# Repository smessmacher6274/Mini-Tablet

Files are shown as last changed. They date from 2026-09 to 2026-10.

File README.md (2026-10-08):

# ESP32 Note Tablet

A touchscreen note pad and to-do display built with an Inland ESP32-WROOM-32E,
a Hosyond 4-inch ST7796S display, and XPT2046 resistive touch. Firmware uses
ESP-IDF and CMake. A local Python server provides a browser task editor,
SQLite storage, and an MQTT broker.

The project began on a Raspberry Pi Pico W; the active firmware is now ESP32.
This README describes the current implementation. The original Pico code is
preserved under `Code/legacy/pico/`.

## Current features

| Feature | Status |
| --- | --- |
| Portrait display | 320 × 480, SPI ST7796S |
| Pen input | Three-point touch calibration at each boot |
| Home menu | To-do list, Draw Notes, Clock |
| Drawing | Black pen, area eraser, Home button |
| Notes across navigation | Preserved in RAM, including the idle screen |
| Idle screen | Appears after 60 seconds without touch; not deep sleep |
| Clock | Placeholder until time is set; automatic time sync is not implemented |
| Computer task editor | Add, edit, complete/reopen, delete, and filter tasks |
| Task storage | SQLite on the computer |
| Wi-Fi/MQTT | Authenticated LAN subscription and tablet receipt status |
| Tablet to-do view | Two tasks per page, Prev/Next; tap a checkbox to complete/reopen online |
| BLE | Greeting plus text task entry; 20 device-local RAM tasks with offline checkboxes |
| BLE Wi-Fi setup | Encrypted SSID/password writes and Apply; settings last until reset |
| iPhone app, dictation, handwriting recognition | Planned |
| Tablet flash persistence | Deferred: notes, tasks, and calibration are not saved by the app |

Display/BLE, navigation, MQTT delivery, task completion and partial redraws have
been confirmed on hardware. BLE task entry builds and passes host tests; its
phone-to-tablet path still needs checking after flashing this update.

## Project layout

```text
2040Bluetooth/
├── README.md                 Main setup and usage guide
├── Code/                     Active ESP-IDF CMake project
│   ├── main/                 Display, touch, UI, BLE, Wi-Fi/MQTT, task parser
│   ├── tests/                Host-side UI and task-parser tests
│   ├── setup_network.py      Generate local firmware network configuration
│   ├── sdkconfig.defaults*   Firmware configuration defaults
│   ├── dependencies.lock    Managed component versions
│   ├── PLAN.md              Earlier detailed roadmap; see status here first
│   └── legacy/pico/         Previous Pico firmware
├── LocalMQTT/                Python server, browser UI, and integration tests
│   ├── server.py             HTTP API + SQLite + embedded aMQTT broker
│   ├── static/               Browser interface
│   ├── setup_lan.py          Generate MQTT credentials and configure LAN IP
│   ├── allow-mqtt.ps1        Windows firewall rule, requires Administrator
│   ├── check_connection.py   Read-only authenticated MQTT connection check
│   ├── run.cmd               Start the Windows server
│   └── data/                 Generated database and local credentials
├── Case/                     Enclosure/pen-holder STL files
└── Kicad/                    Reserved for electronics design files
```

Generated build folders and the old Pico SDK may also be present. Always run
ESP-IDF commands from **Code**, not the workspace root. This guide uses
`Code/build-esp32-wsl`; `compile.sh` instead defaults to `Code/build-esp32`.

## Hardware and wiring

Use the **GPIO/IO labels**, not physical header positions. Disconnect USB before
rewiring. These connections target the original ESP32-WROOM-32E, not ESP32-S3.

| Display pin | ESP32 connection |
| --- | --- |
| VCC | 5V, for the project's identified display module |
| GND | GND |
| CS | IO27 |
| RESET / RST | IO25 |
| DC / RS | IO26 |
| SDI / MOSI | IO23 |
| SCK | IO18 |
| LED | 3V3 |
| SDO / MISO | Leave disconnected |
| T_CLK | IO14 |
| T_DIN | IO13 |
| T_DO | IO19 |
| T_CS | IO32 |
| T_IRQ | IO33 |

ESP32 GPIO signals are 3.3V; do not apply 5V to signal pins. Confirm the supply
requirements if using a different display module. The LCD uses SPI2 at 1 MHz;
touch uses a separate SPI3 bus. Keep the touch wires on the pins above.

Both modules need secure, soldered headers. Direct jumpers resolved the earlier
white-screen problem; the breadboard or a jumper was suspected. A lit backlight
does not prove that SPI communication works. Pin definitions are in
[`Code/main/board.h`](Code/main/board.h).

## How the current connection works

```text
Computer browser at localhost:8080
                  |
          HTTP API + SQLite
                  |
       MQTT broker on computer
                  |
         Home router / LAN
                  |
         ESP32 Wi-Fi client
                  |
         Tablet to-do screen
```

The ESP32 joins your existing 2.4 GHz Wi-Fi. It does **not** create a network
that appears in the computer's Wi-Fi list. The computer may use Ethernet or
another Wi-Fi band if both devices can communicate on the same LAN.

`localhost` means the computer where the browser/server runs. The ESP32 uses
the computer's **LAN IPv4 address**, not localhost and not the public internet
IP. `192.168.1.148` was the development computer's address; confirm it using
Windows `ipconfig` under the active Wi-Fi/Ethernet adapter.

The computer must remain awake with the server running for syncing. The tablet
keeps its last received tasks in RAM during disconnection; after reboot it
needs to reconnect to receive them again. The phone is not part of this path yet.

## 1. Start the local server — Windows PowerShell

The following paths match this development computer; change them for another
checkout. Python 3.11 was used for the verified server environment.

For a fresh environment:

```powershell
cd C:\Users\messm\OneDrive\Desktop\2040Bluetooth\LocalMQTT
python -m venv .venv
.\.venv\Scripts\python.exe -m pip install -r requirements-lock.txt
```

Skip those installation steps if `.venv` is already installed. Provision the
LAN address and start the server:

```powershell
ipconfig
# Replace this address if your active adapter shows a different IPv4 address.
.\.venv\Scripts\python.exe setup_lan.py --host 192.168.1.148
.\.venv\Scripts\python.exe server.py --lan
```

Open [http://localhost:8080](http://localhost:8080). Leave the terminal running;
Ctrl+C stops it. On later runs, double-click `LocalMQTT/run.cmd` or run the final
command above. Run only one server instance. If the page is already available,
check the existing instance before launching another.

The server also supports loopback-only development without `--lan`, but the
ESP32 cannot connect to that mode. MQTT LAN mode uses generated credentials and
topic permissions; HTTP remains accessible only on the computer.

### Allow MQTT through Windows Firewall

Run once from **Administrator PowerShell**:

```powershell
cd C:\Users\messm\OneDrive\Desktop\2040Bluetooth\LocalMQTT
powershell.exe -NoProfile -ExecutionPolicy Bypass -File .\allow-mqtt.ps1
```

This allows inbound TCP 1883 to the configured LAN address from the local
subnet. The execution-policy override applies only to that command's process.
The earlier automatic firewall attempt lacked Administrator rights; do not
assume the rule exists until this succeeds.

## 2. Configure and flash the tablet — WSL Bash

The verified firmware toolchain is the installed ESP-IDF 6.1 development
checkout at `~/esp32/esp-idf`. It uses the **esp32** target, not esp32s3.
See [Espressif's setup guide](https://docs.espressif.com/projects/esp-idf/en/stable/esp32/get-started/index.html)
for a new toolchain installation. Activate the existing installation in each
new WSL shell:

```bash
source ~/esp32/esp-idf/export.sh
idf.py --version
```

If activation reports that its Python virtual environment is missing:

```bash
cd ~/esp32/esp-idf
./install.sh esp32
source ./export.sh
```

Connect the ESP32 USB device to WSL using your USB forwarding setup. Windows
COM5 and WSL `/dev/ttyUSB0` are names on different operating systems; use the
port that actually appears in your current shell:

```bash
ls /dev/ttyUSB* /dev/ttyACM* 2>/dev/null
```

Configure the firmware, then build and flash:

```bash
cd /mnt/c/Users/messm/OneDrive/Desktop/2040Bluetooth/Code
python3 setup_network.py
idf.py -B build-esp32-wsl -p /dev/ttyUSB0 flash monitor
```

The setup script asks for the Wi-Fi network name, a hidden Wi-Fi password, and
the computer LAN IP. Press Enter to accept the bracketed IP if it is correct.
It imports the MQTT credentials from `LocalMQTT/data/connection.json` and writes
`Code/main/network_config.h`. That header is required for compilation; missing
or empty network settings must be corrected before building. Older builds
silently disabled Wi-Fi and displayed `WIFI NOT SET` when it was missing.

Build without flashing with `idf.py -B build-esp32-wsl build`. ESP32 output is
flashed over serial; do not look for a Pico-style `.uf2` file. Exit the serial
monitor with **Ctrl+]**. If automatic flashing cannot connect, hold BOOT during
connection and release when flashing begins.

## Daily use

1. Start the computer server and leave it running.
2. Power the tablet. Hold the stylus on each red cross, then lift when it advances.
   These three points map raw touch readings to screen coordinates.
3. Tap the idle screen to open the menu.
4. Open **To-do List** to see tasks, completion state, and Prev/Next pages.
   Tap and lift on a checkbox to complete/reopen a task. The box changes after
   server confirmation; keep the server running. Offline taps are not queued.
5. Add or change tasks in the computer browser. The tablet receives new snapshots.
6. Open **Draw Notes** to draw. Tap and lift on **Write**, **Erase**, or **Home**.
   Erase is an area eraser, not a whole-page clear button.

The note survives Home and the 60-second idle timeout. Power loss/reset clears
it and restarts calibration. The idle screen does not turn off the backlight.
Task titles support up to 120 UTF-8 bytes on the server, with at most 50 tasks;
the tablet's bitmap font substitutes `?` for unsupported characters.

To-do updates use partial redraws: completion repaints only the affected checkbox
and text; title changes clear that row. Unchanged snapshots do not repaint the
list. Page changes repaint the list area while keeping navigation buttons.
The display SPI clock remains at the conservative 1 MHz setting.

Successful connection logs include `Wi-Fi ready`, `MQTT connected`, and
`Received ... tasks`. Browser status distinguishes publication to the broker
from the revision received by the tablet. Receipt confirms arrival in the
tablet's RAM queue, not a flash write or proof that pixels have been rendered.

## BLE and the proposed iPhone workflow

Current BLE service:

| Setting | Value |
| --- | --- |
| Advertising name | `NoteTablet-BLE` |
| Service UUID | `12345678-1234-5678-1234-56789abcdef0` |
| Read characteristic | `12345678-1234-5678-1234-56789abcdef1` |
| Greeting | `What it do` |

Use a BLE GATT scanner to read the greeting and write tasks. This is a custom
GATT service, not a keyboard/audio profile. BLE stays enabled with Wi-Fi/MQTT.

Portable task entry is now available through a BLE testing app: write plain
text to characteristic `12345678-1234-5678-1234-56789abcdef2`. Local tasks can
be completed offline and survive phone disconnects and MQTT updates, but not
reset. They are not uploaded to the computer yet. See [BLE setup and protocol](Code/BLE.md).
The greeting remains at `...def1`; write status is readable at `...def3`.
BLE Wi-Fi configuration uses characteristics `...def4` through `...def7`; see
the BLE guide for pairing, write order, and status. Settings last until reset.
A polished companion app and persistent network configuration are future features.
MQTT still runs over Wi-Fi/TCP, independently of BLE.

## Data, credentials, and protocol

- `LocalMQTT/data/tasks.sqlite3`: authoritative tasks and revisions on the PC.
- `LocalMQTT/data/connection.json`: local MQTT credentials and server address.
- `LocalMQTT/data/passwords.txt`: broker password hashes.
- `Code/main/network_config.h`: generated Wi-Fi/MQTT configuration.

Credential files are ignored by their component `.gitignore` files. Compiled
firmware also contains credentials; do not publish it or those files. Back up
the database with the server stopped. Tablet drawings are not in this database.

MQTT uses retained QoS 1 snapshots at
`notepad/v1/devices/tablet-001/state`. The tablet publishes heartbeat/received
revision at `notepad/v1/devices/tablet-001/presence`, including an offline Last
Will. The service is allowed to publish state; tablet credentials cannot edit
it directly. Completion requests use non-retained QoS 1 messages at
`notepad/v1/devices/tablet-001/commands`, with an item ID, base revision, and
explicit desired completion state. Stale requests are rejected and current
state is republished; repeated messages cannot toggle a task twice.
Server restart reconstructs retained state from SQLite.

This is a trusted-LAN prototype using unencrypted MQTT. Do not port-forward it
to the internet. The browser editor is localhost-only, so opening the same URL
on an iPhone will not reach this computer.

See [`LocalMQTT/README.md`](LocalMQTT/README.md) for the JSON snapshot format,
HTTP API, process management, and server details.

## Troubleshooting

| Symptom | What to check |
| --- | --- |
| No ESP32 network in the Wi-Fi list | Expected: the tablet joins your router; it is not an access point. |
| `idf.py: command not found` | Source the WSL ESP-IDF `export.sh` in this terminal. |
| PowerShell syntax errors in Bash | Use WSL commands in Bash and Windows commands in PowerShell. |
| `CMakeLists.txt not found` | Change into the project's `Code` directory. |
| No `/dev/ttyUSB0` | Check USB cable and USB forwarding into WSL; COM5 is a Windows name. |
| Port not readable | Check `ls -l /dev/ttyUSB0` and serial-group membership; if owned by `dialout`, add your user with `sudo usermod -aG dialout "$USER"`, then start a new login session. |
| `WIFI NOT SET` | Run `setup_network.py`, rebuild, and flash. |
| `WIFI CONNECTING` | Verify SSID/password and 2.4 GHz availability. |
| `MQTT CONNECTING` | Check server `--lan`, LAN IP, firewall, and router client isolation. |
| White display but BLE works | Check LCD power, ground, CS/DC/reset/SPI wires; previously direct jumpers fixed this. |
| Calibration does not advance | Check the separate touch wiring, especially T_IRQ and T_CS. |
| Notes disappear after reboot | Expected until flash persistence is implemented. |
| Port 8080/1883 is occupied | An existing server may already be running; see the server README before stopping it. |

If the computer LAN IP changes, rerun `setup_lan.py --host NEW_IP`, restart the
server, rerun the firewall script, then rerun tablet setup and flash. Updating
only the firmware IP does not change the server's listening address.

## Validation and development

Server integration tests use temporary databases and MQTT clients:

```powershell
cd C:\Users\messm\OneDrive\Desktop\2040Bluetooth\LocalMQTT
.\.venv\Scripts\python.exe -m unittest -v test_server
.\.venv\Scripts\python.exe check_connection.py
```

The connection check requires the real server running. It verifies authenticated
subscription on its LAN address without editing tasks; it does not prove the
Windows firewall admits traffic from another device.

Host UI/parser tests in WSL, from `Code` (managed cJSON is fetched by ESP-IDF
during the firmware build):

```bash
gcc -std=gnu11 -Itests/stubs -Imain tests/ui_test.c main/ui.c -o /tmp/tablet-ui-test
/tmp/tablet-ui-test
gcc -std=gnu11 -Imain -Imanaged_components/espressif__cjson/cJSON tests/todo_test.c main/todo_model.c managed_components/espressif__cjson/cJSON/cJSON.c -o /tmp/tablet-todo-test
/tmp/tablet-todo-test
```

Previously verified: ESP32 MQTT firmware build; UI navigation, input suppression,
pagination, note restore, and idle tests; task-parser tests; four server tests
covering CRUD, revisions, validation, retained delivery, restart, authentication,
topic permissions, and presence. Hardware tests remain necessary after flashing.

## Next milestones

1. Confirm portable BLE task entry on the physical tablet and iPhone.
2. Add an iPhone companion app and synchronize device-local tasks with the server.
3. Add shared task IDs, acknowledgments, and conflict handling before two-way edits.
4. Add persistent Wi-Fi configuration and real clock/timezone synchronization.
5. Add flash persistence for calibration, tasks, and note pages when ready.
6. Add multiple notes and export; handwriting-to-text is a later feature.

The earlier design is retained in [`Code/PLAN.md`](Code/PLAN.md). Its proposed
cloud/web-app and Mosquitto architecture is not the current deployment; today
the broker is embedded aMQTT and the browser editor runs locally on the PC.

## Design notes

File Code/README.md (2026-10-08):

# ESP32 note tablet: portrait ST7796S + BLE

Current build defaults to Bluetooth test mode: boot directly to To-do, skip
calibration, disable touch, Wi-Fi and MQTT, and keep the screen awake.
Wi-Fi credential characteristics are omitted during this test. See [BLE.md](BLE.md)
for the stability checks. Set `TABLET_BLE_TEST_MODE` to 0 in `main/test_mode.h`
to restore the calibration/menu/idle behavior described below.

## Current milestone: MQTT task display

See `PLAN.md` for the iPhone / MQTT roadmap and synchronization design.
After calibration, tap the idle clock screen to open the menu. Choose To-do
List or Draw Notes. Notes has Write, Erase and Home controls. Drawings survive
navigation and the 60-second idle timeout in a 16,960-byte monochrome RAM buffer.
Reset/power loss still clears the note. The idle screen is not hardware sleep.

The To-do view receives the computer's list over Wi-Fi/MQTT, with two tasks per
page and Prev/Next controls. Tap a checkbox to complete/reopen while connected;
the server-confirmed snapshot updates the display. Titles are edited in the browser.
See `../LocalMQTT/README.md` for the server and Windows firewall setup.
Run `python3 setup_network.py` in this directory before flashing to enter Wi-Fi
credentials locally and import the generated MQTT credentials. This configuration
is required to build; older firmware silently disabled Wi-Fi when it was missing.
The clock still displays `--:--` / `TIME NOT SET`; time synchronization is later.
BLE now supports text task entry from a phone testing app, with offline local
checkboxes. See [BLE.md](BLE.md). Local tasks remain in RAM and are separate
from the computer's list; a companion app and cross-transport sync are later.

Flash from the activated WSL shell, inside the **Code** directory:

```bash
idf.py -B build-esp32-wsl -p /dev/ttyUSB0 flash monitor
```

Validation: host UI tests cover tap/release suppression across navigation,
Write/Erase switching, note-restore calls, and inactivity return to the clock.
Hardware check: draw, return Home, revisit Notes, erase, wait 60 seconds, then
open Notes again and confirm the image survives. Reset should clear it.

Target hardware: **Inland ESP32 board with ESP32-WROOM-32E module**.
The project now uses ESP-IDF (CMake), not the Pico SDK or Arduino.
The MQTT build is verified with your ESP-IDF 6.1 development checkout.
ESP32-S3 also has an optional pin map,
but the default and the wiring below are for your original ESP32.
No PSRAM is required or enabled. Default flash size is a conservative 4 MB;
confirm actual flash size before increasing it.

## Wire the display (USB disconnected)

These are **GPIO labels**, not header position numbers. Do not retain the Pico
physical-pin wiring. Check labels on the Inland board before connecting.

| ST7796S module | ESP32-WROOM-32E development board |
| --- | --- |
| VCC | USB-derived 5V supply pin, after confirming the board pinout |
| GND | GND |
| CS | GPIO27 |
| RESET / RST | GPIO25 |
| DC / RS | GPIO26 |
| SDI / MOSI | GPIO23 |
| SCK | GPIO18 |
| LED | 3V3 |
| SDO / MISO | Unconnected |
| Touch pins | See pen-tracing section below |

The previously identified display module accepts 3.3–5V VCC; its LED control
uses 3.3V. ESP32 signal pins use 3.3V: never connect 5V to a GPIO.
Use soldered headers and secure short jumpers. Remove any SD card for this test.
The white-screen fault on the earlier wiring is not proven fixed by this port.
A lit backlight does not establish that the LCD controller has stable power.

## Install and activate ESP-IDF

Use Espressif's official setup instructions for ESP-IDF 5.4 and your OS:
https://docs.espressif.com/projects/esp-idf/en/v5.4/esp32/get-started/index.html

The Arm compiler used for the Pico cannot compile this Xtensa ESP32 project.
In Linux/WSL, after installing ESP-IDF, activate it in each new shell:

```bash
source ~/esp/esp-idf/export.sh
```

On Windows, use the ESP-IDF terminal installed by Espressif. Native Windows
flashing is often simpler than forwarding a USB serial device into WSL.

## Build and flash

From this project directory in an activated ESP-IDF shell:

```bash
idf.py -B build-esp32 set-target esp32
idf.py -B build-esp32 build
idf.py -B build-esp32 -p /dev/ttyUSB0 flash monitor
```

Replace `/dev/ttyUSB0` with your board's serial port (`COM5`, for example, in
Windows). If automatic flashing fails, hold BOOT while connecting/resetting
and release when flashing begins. Exit the serial monitor with Ctrl+].
ESP32 uses serial flashing, not Pico BOOTSEL/UF2 drag-and-drop.

For subsequent Bash builds, `bash compile.sh` runs the build without deleting
anything. The old `build/` and `build-display/` directories contain Pico output;
do not use those binaries for the ESP32. The new build is `build-esp32/`.

## What to expect

- Portrait 320x480 screen with Hello and World! on separate lines and RGB bars.
- BLE device named **NoteTablet-BLE** (previously PicoW-BLE).
- Service: `12345678-1234-5678-1234-56789abcdef0`.
- Read characteristic: `12345678-1234-5678-1234-56789abcdef1`.
- Readable text: **What it do**, preserving your latest greeting edit.
- Advertising resumes after disconnection or a failed connection attempt.

Test by power cycling, leaving the display running for several minutes, reading
via a BLE scanner, disconnecting, and reconnecting. Check serial logs for resets
or brownout reports if the screen goes white. This demo has no pairing requirement
and no writable notes, persistent storage, or Wi-Fi yet.

## Source layout

- `main/main.c`: initialize the display once, then start BLE.
- `main/display.c`: SPI ST7796S driver, 1 MHz, RGB565, portrait; small scanline buffer.
- `main/board.h`: wiring by chip target.
- `main/ble.c`: NimBLE GATT service and connection/advertising callbacks.
- `sdkconfig.defaults`: BLE and build defaults, no dependency on PSRAM.

NimBLE runs in its own FreeRTOS task; no Pico async polling loop is needed.
The repeated display-reset loop found in your latest Pico code is not carried
into the ESP32 app. Only the display code owns SPI2; touch/SD integration later
will need shared-bus coordination. NVS currently contains only system data;
its initialization may erase/reinitialize NVS on a format/full-pages error.
Revisit that policy before storing user notes there.

The previous Pico sources, including your edits, are saved in `legacy/pico/`.
The Pico SDK and old build directories are left in place but unused. To rebuild
that snapshot, set PICO_SDK_PATH to the existing SDK and configure it separately.

Optional ESP32-S3 pin map: CS=10, MOSI=11, SCK=12, DC=9, RESET=8. Select it only
for actual S3 hardware with `idf.py -B build-esp32 set-target esp32s3`; changing
target regenerates sdkconfig. Do not use those pins on your WROOM-32E.

## Validation status

The port has been source-reviewed against ESP-IDF 5.4 NimBLE and SPI APIs.
The pen-tracing firmware compiled successfully with the installed WSL ESP-IDF 6.1 development checkout. Display/BLE operation was confirmed by the user before this change; touch calibration and drawing still need hardware verification.

References:
- https://github.com/espressif/esp-idf/tree/v5.4.2/examples/bluetooth/nimble/bleprph
- https://docs.espressif.com/projects/esp-idf/en/v5.4/esp32/api-reference/peripherals/spi_master.html

## Pen tracing (XPT2046 resistive touch)

Keep the working display connections. With USB unplugged, add these five
connections for the ESP32-WROOM-32E (GPIO labels, not header positions):

| Display touch pin | ESP32 |
| --- | --- |
| T_CLK | IO14 |
| T_DIN | IO13 |
| T_DO | IO19 |
| T_CS | IO32 |
| T_IRQ | IO33 |

Touch uses a separate SPI3 bus at 500 kHz. Do not connect T_CLK/T_DIN to the
LCD bus in this configuration. LCD SDO remains disconnected. If your display
has CTP_* labels instead of T_*, this driver is not for that touch variant.

Build/flash in the activated WSL ESP-IDF shell:

```bash
idf.py -B build-esp32-wsl -p /dev/ttyUSB0 flash monitor
```

At each boot the hello screen is followed by three red calibration crosses:
upper left, upper right, then lower left. Hold the stylus steadily on each cross
until it disappears, then lift. After all three, a white canvas appears; draw
with moderate stylus pressure to leave a black trace. It does not recognize
handwriting or save strokes yet. Press EN/reset to clear and recalibrate.
BLE remains active during calibration and drawing. If the first cross never
advances, check T_IRQ, T_CS and the other touch wires. The serial monitor logs
each calibration target and canvas readiness. Small sample filtering and a
three-point affine transform handle axis reversal and portrait orientation.

## Write and Erase tools

After calibration, the top toolbar has Write and Erase buttons. The selected
button is green. Tap and lift to select a tool, then use the canvas below:
Write draws a 3-pixel black stroke; Erase rubs out a 17-pixel-wide area.
Switching tools keeps the rest of the drawing. Neither tool can paint over
the toolbar. Reset still clears the page and restarts calibration; BLE stays on.

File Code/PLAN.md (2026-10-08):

# Note tablet roadmap

## Current priorities (October 5, 2026)

1. Stabilize Bluetooth, investigate duplicate task entry, and verify reconnects
   without power cycling. Temporarily skip calibration and idle clock switching.
2. Wire and bring up microSD external storage after confirming module/pin usage.
3. Persist received MQTT task state on the server and/or microSD.
4. Save touch calibration to flash/SD and restore it at boot.
5. Improve display refresh rates.
6. Synchronize and finish the clock.

Bluetooth soak-test mode is currently enabled in `main/test_mode.h`;
the normal product flow below resumes when it is disabled.

## Product flow

Boot -> touch calibration -> idle clock -> tap -> menu -> To-do or Notes.
Home returns to menu; Clock returns to idle. After 60 seconds without touch,
return to the clock. Preserve the current note across screen changes. This
idle screen is a UI state, not deep sleep: the existing backlight wiring stays on.

The owner uses an iPhone and has no existing MQTT infrastructure.

Local computer milestone implemented in `../LocalMQTT/`: browser CRUD, SQLite
persistence, retained MQTT state and restart/duplicate/conflict tests. The first
broker is embedded aMQTT to avoid an additional Docker/Mosquitto installation.
It binds only to loopback; ESP32 subscription and authenticated LAN access remain
next steps. This changes the initial broker implementation, not the MQTT format.

## Architecture

iPhone web app -> HTTPS API -> synchronization service + SQLite database
                                      |
                                  MQTT broker
                                      |
                              ESP32 over Wi-Fi

Start with Mosquitto and a small service on the development computer on the
same LAN. The host must remain running and reachable. Later move them to an
always-on machine or hosted service for access away from home. Do not expose
an unauthenticated broker publicly. Use per-device credentials/topic ACLs and
TLS outside an isolated local development setup. BLE remains available during
development; MQTT uses Wi-Fi, not the existing BLE greeting characteristic.

Use an iPhone-friendly web app first (add to Home Screen if desired). Text
entry can use the iPhone keyboard's dictation. No browser SpeechRecognition
dependency for the first release. Native iOS app/background notifications are
a later decision. Drawings stay separate from tasks until the user approves
recognized text. Handwriting recognition runs on the server/phone, not ESP32.

## Milestones and acceptance

1. **Device navigation foundation (current implementation)**
   - Clock state, tap-to-menu, To-do screen, Notes with Write/Erase/Home.
   - Honest unset clock until a real time source exists.
   - Monochrome note buffer survives menu/idle changes in RAM, not power loss.
   - No fake synchronized tasks; empty To-do view until storage/sync is added.
   - Check tap release does not activate the next screen; toolbar cannot be drawn on.
2. **Offline data and time**
   - Save calibration with an explicit recalibration path.
   - Task IDs, list IDs, title, completion, revision; local flash persistence.
   - Persist note pages (1-bit bitmap initially, versioned format).
   - Wi-Fi setup, SNTP UTC time, explicit timezone/DST setting; resync after reboot.
   - Verify reboot preservation, missing Wi-Fi, full storage and write failures.
3. **Local broker and durable synchronization**
   - Mosquitto plus a small service and SQLite, reproducible local startup.
   - Add ESP-MQTT managed component for ESP-IDF 6.x.
   - Server is authoritative; ESP caches confirmed state and queues offline operations.
   - Read/list, create, rename, complete/reopen and delete tasks and lists.
   - Verify duplicated, delayed, reordered messages and reconnection/reboot.
4. **iPhone input**
   - Responsive list UI: type/dictate, review, submit, then see delivery status.
   - Same account/device association as broker authorization; no credentials in JS.
   - Test iPhone on same LAN, then design remote access before deployment.
5. **Notes, then recognition (last)**
   - Multiple persistent pages, export/upload and backup, explicit clear/delete.
   - Recognition returns editable draft text; never overwrites the original image.
   - User explicitly chooses whether to turn recognized text into tasks.

## Proposed MQTT contract (design, not yet implemented)

Prefix: `notepad/v1/devices/<device-id>/`.

| Topic | Publisher | Semantics |
| --- | --- | --- |
| commands | ESP -> server | Non-retained QoS 1 operations with operation_id |
| acknowledgements | server -> ESP | Non-retained QoS 1 result + operation_id |
| state | server -> ESP | Retained QoS 1 versioned snapshot for small bounded lists |
| presence | ESP -> server | Retained online status, offline Last Will |

Each operation includes schema_version, operation_id, entity_id, operation type,
and base_revision. Server applies each operation_id once. Completion uses explicit
`completed: true/false`, never a toggle command that could repeat. Detect stale
base revisions and return a conflict instead of silently losing edits. Device
ignores older snapshots. UI distinguishes locally pending vs server-confirmed.
Set limits for number of tasks, UTF-8 title bytes and message size; reject invalid
payloads. Assemble fragmented MQTT events before parsing. Large note images use
HTTP upload or a separate chunk protocol, not unbounded retained state payloads.

## Implementation constraints

ESP32-WROOM-32E, 320x480 ST7796S, XPT2046 touch, no assumed PSRAM.
Only the UI task draws/reads touch. Network callbacks deliver bounded queued
events to the UI. Avoid blocking networking on flash writes or full-screen redraw.
Use a 1-bit canvas (~17 KB) rather than a 307 KB RGB framebuffer.
Don't erase all NVS automatically once real user data is stored there.

References:
- https://docs.espressif.com/projects/esp-idf/en/stable/esp32/api-reference/protocols/mqtt.html
- https://mosquitto.org/documentation/

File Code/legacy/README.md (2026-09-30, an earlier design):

Original Pico source snapshot, including local edits at migration time.
CMake source directory: legacy/pico. Set PICO_SDK_PATH to the root pico-sdk folder.
The repeated display initialization in this snapshot reflects the pre-port code;
it is retained for reference, not recommended for normal operation.

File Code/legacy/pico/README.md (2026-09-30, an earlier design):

# Pico W Bluetooth with CMake

## ST7796S display hello world

The firmware now draws `Hello World!` on two lines in 320x480 portrait with red, green, and blue
test bars, then starts the same BLE service. Display initialization takes about
two seconds. Touch is not enabled. Drawing runs once before radio startup;
the existing BLE polling loop remains unchanged. Future live screen updates
must be broken into short operations so BLE continues to be serviced.

Wiring: CS=GP17 (22), SCK=GP18 (24), MOSI=GP19 (25), RESET=GP20 (26),
DC=GP21 (27). Parentheses indicate Pico physical pins. For the previously
identified 3.3–5V module, VCC=VBUS (40), GND=GND (38), LED=3V3 OUT (36).
MISO, touch, and SD connections are unused. Power off before changing wiring.

Rebuild from your existing Bash environment:

```bash
cmake --build build --parallel
```

Flash `build/picow_bluetooth.uf2` using BOOTSEL. Verify the text and RGB bars,
then connect to `PicoW-BLE` and read the greeting as before. Disconnect and
reconnect to check BLE remains functional. If only the backlight appears,
check CS/DC/RESET/MOSI/SCK against the labels and confirm the ST7796S driver.
The SPI clock is reduced to 1 MHz in `display.c` to provide more margin with
jumper wires. This is a diagnostic mitigation, not a confirmed white-screen fix.
There is no display timeout or clear operation after the startup image.
If it turns white, check whether BLE still responds, and whether a full USB
power cycle restores the image. With power disconnected, reseat VCC, ground,
RESET (GP20/physical 26), CS, and the SPI connections. A lit backlight alone
does not confirm that the LCD controller has stable power or is out of reset.

This starter targets the **Raspberry Pi Pico W / WH (RP2040 + CYW43439)**.
The RP2040 chip itself has no radio; a different RP2040 board needs a compatible
radio and driver. This is a BLE peripheral, not Bluetooth Classic serial or audio.
It advertises as `PicoW-BLE` and exposes a readable `Hello from Pico W!` value.

## Windows prerequisites

Install CMake, Ninja, Python 3, Git, and the Arm GNU bare-metal toolchain
(`arm-none-eabi-gcc`). Put their executables on PATH and reopen PowerShell.
Use the Arm toolchain, not the Windows/MSVC compiler. The Raspberry Pi Pico
VS Code extension can also provision the Pico development tools.

## Configure and build

Run from this project folder. Use a current stable Pico SDK with its submodules:

```powershell
git clone --recurse-submodules https://github.com/raspberrypi/pico-sdk.git
$env:PICO_SDK_PATH = (Resolve-Path .\pico-sdk).Path
cmake -S . -B build -G Ninja -DPICO_BOARD=pico_w
cmake --build build --parallel
```

If you already have the SDK, set `PICO_SDK_PATH` to that folder instead of cloning.
For an existing incomplete checkout, run:

```powershell
git -C "$env:PICO_SDK_PATH" submodule update --init --recursive
```

CMake generates `service.h` from `service.gatt` using Python; do not create it
manually. `pico_btstack_ble` supplies BLE, `pico_btstack_cyw43` connects BTstack
to the radio, and `pico_cyw43_arch_none` provides radio integration without Wi-Fi.

## Flash and verify

1. Hold BOOTSEL while plugging the Pico W into USB. Release when `RPI-RP2` appears.
2. Copy `build/picow_bluetooth.uf2` to that drive. The board reboots automatically.
3. Open a BLE GATT scanner on your phone, scan, and connect to `PicoW-BLE`.
   Use the scanner's connection flow; operating-system Bluetooth pairing is not needed.
4. Open service `12345678-1234-5678-1234-56789abcdef0` and read characteristic
   `12345678-1234-5678-1234-56789abcdef1`. Decode as UTF-8 to see the greeting.
5. Disconnect and scan again to verify reconnection.

USB serial logging is enabled. Startup logs can occur before a terminal connects;
BLE advertising does not wait for a terminal. This demo has no pairing requirement
and its test value is publicly readable while connected.

## Troubleshooting

- `cmake`, `ninja`, or `arm-none-eabi-gcc` not recognized: install the missing
  prerequisite or add its `bin` directory to PATH.
- Missing BTstack/CYW43 files: initialize SDK submodules and check `PICO_SDK_PATH`.
- Changed SDK, compiler, or board: configure into a fresh build directory.
- Device absent: confirm it is a Pico W, use a data-capable USB cable, and check
  phone Bluetooth/scanner permissions. The ordinary Pico has no onboard Bluetooth.

## References and validation

- SDK: https://github.com/raspberrypi/pico-sdk
- Official Bluetooth examples: https://github.com/raspberrypi/pico-examples
- SDK networking libraries: https://www.raspberrypi.com/documentation/pico-sdk/networking.html

The display-plus-BLE firmware was successfully compiled using the WSL Arm
toolchain in `build-display/`. The ready-to-flash file is
`build-display/picow_bluetooth.uf2`. Hardware behavior still needs verification
on the connected screen and Pico W. The SDK emits an existing ENABLE_BLE
redefinition warning; it does not prevent the build.

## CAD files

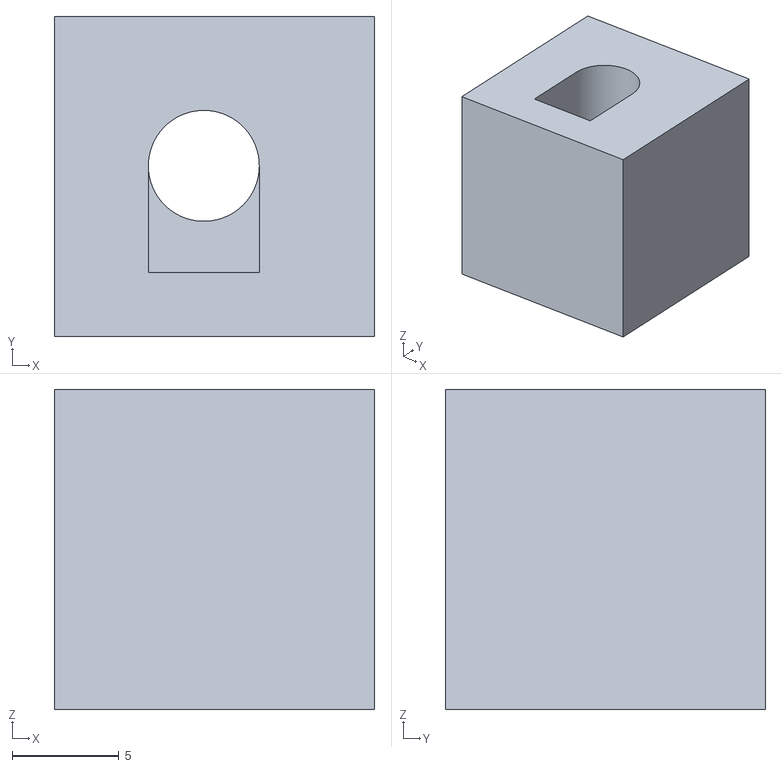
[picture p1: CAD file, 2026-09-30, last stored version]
Case/penholder hole.stl
15.0 x 15.0 x 15.0

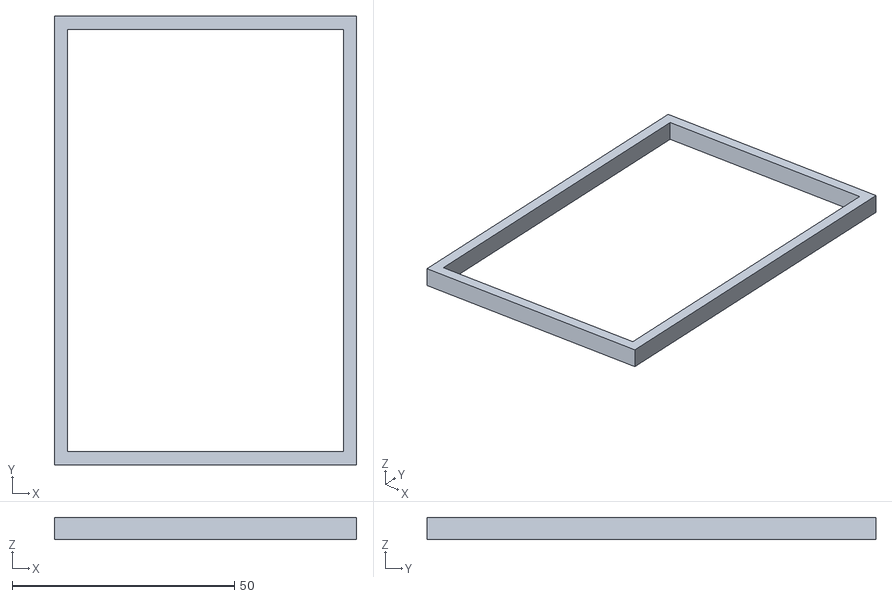
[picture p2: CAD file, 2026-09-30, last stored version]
Case/Case.stl
68.0 x 101.0 x 5.00

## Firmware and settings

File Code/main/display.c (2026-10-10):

#include "display.h"
#include "board.h"
#include "driver/gpio.h"
#include "driver/spi_master.h"
#include "esp_check.h"
#include "freertos/FreeRTOS.h"
#include "freertos/task.h"
#include <string.h>
#include <stdlib.h>
#include <ctype.h>

enum { CS = TFT_CS, SCK = TFT_SCK, MOSI = TFT_MOSI, RESET = TFT_RST, DC = TFT_DC,
       WIDTH = 320, HEIGHT = 480 };

static spi_device_handle_t display_spi;
// One bit per canvas pixel. Navigation redraws do not change this buffer.
static uint8_t note_bits[(320 * (480 - CANVAS_TOP) + 7) / 8];
static void sleep_ms(unsigned ms) {
    vTaskDelay(pdMS_TO_TICKS(ms) + 1);
}

static void gpio_put(int pin, int level) {
    ESP_ERROR_CHECK(gpio_set_level(pin, level));
}

static void write_bytes(const uint8_t *data, size_t size) {
    spi_transaction_t transaction = {
        .length = size * 8,
        .tx_buffer = data,
    };
    ESP_ERROR_CHECK(spi_device_polling_transmit(display_spi, &transaction));
}

static void command(uint8_t cmd, const uint8_t *data, size_t count) {
    gpio_put(CS, 0);
    gpio_put(DC, 0);
    write_bytes(&cmd, 1);
    if (count) {
        gpio_put(DC, 1);
        write_bytes(data, count);
    }
    gpio_put(CS, 1);
}

#define CMD(c, ...) do { const uint8_t d[] = {__VA_ARGS__}; \
    command((c), d, sizeof(d)); } while (0)

static void fill(unsigned x, unsigned y, unsigned w, unsigned h, uint16_t color) {
    if (x >= WIDTH || y >= HEIGHT || !w || !h) return;
    if (w > WIDTH - x) w = WIDTH - x;
    if (h > HEIGHT - y) h = HEIGHT - y;
    unsigned right = x + w - 1, bottom = y + h - 1;
    CMD(0x2A, x >> 8, x, right >> 8, right);
    CMD(0x2B, y >> 8, y, bottom >> 8, bottom);
    // One scanline keeps RAM available for BLE and needs no external PSRAM.
    uint8_t row[WIDTH * 2];
    for (unsigned i = 0; i < w; ++i) {
        row[2 * i] = color >> 8;
        row[2 * i + 1] = color;
    }
    uint8_t write_memory = 0x2C;
    gpio_put(CS, 0);
    gpio_put(DC, 0);
    write_bytes(&write_memory, 1);
    gpio_put(DC, 1);
    for (unsigned j = 0; j < h; ++j) {
        write_bytes(row, w * 2);
        // Allow the idle task to run during a full-screen fill at 1 MHz.
        if ((j & 15u) == 15u) vTaskDelay(1);
    }
    gpio_put(CS, 1);
}

// Small original 5x7 font: only the characters needed for this demo.
static const char letters[] = "HeloWrd!itEas";
static const uint8_t glyphs[][7] = {
    {17,17,17,31,17,17,17}, // H
    {0,0,14,17,31,16,14},  // e
    {12,4,4,4,4,4,14},     // l
    {0,0,14,17,17,17,14},  // o
    {17,17,17,21,21,21,10},// W
    {0,0,22,25,16,16,16},  // r
    {1,1,15,17,17,17,15},  // d
    {4,4,4,4,4,0,4},       // !
    {4,0,12,4,4,4,14},     // i
    {4,4,14,4,4,4,3},      // t
    {31,16,16,30,16,16,31},// E
    {0,0,14,1,15,17,15},   // a
    {0,0,15,16,14,1,30},   // s
};

static void text(unsigned x, unsigned y, const char *s, unsigned scale) {
    for (; *s; ++s, x += 6 * scale) {
        const char *p = strchr(letters, *s);
        if (!p) continue;
        const uint8_t *g = glyphs[p - letters];
        for (unsigned row = 0; row < 7; ++row)
            for (unsigned col = 0; col < 5; ++col)
                if (g[row] & (1u << (4 - col)))
                    fill(x + col * scale, y + row * scale, scale, scale, 0xffff);
    }
}

void display_clear(void) { fill(0, 0, WIDTH, HEIGHT, 0xffff); }

void display_rect(unsigned x, unsigned y, unsigned w, unsigned h, unsigned short color) {
    fill(x, y, w, h, color);
}

// Original 5x7 uppercase UI font, A-Z followed by 0-9 and punctuation.
static const char ui_letters[] = "ABCDEFGHIJKLMNOPQRSTUVWXYZ0123456789:-/.?";
static const uint8_t ui_font[][7] = {
    {14,17,17,31,17,17,17}, {30,17,17,30,17,17,30},
    {14,17,16,16,16,17,14}, {30,17,17,17,17,17,30},
    {31,16,16,30,16,16,31}, {31,16,16,30,16,16,16},
    {14,17,16,23,17,17,15}, {17,17,17,31,17,17,17},
    {14,4,4,4,4,4,14}, {7,2,2,2,18,18,12},
    {17,18,20,24,20,18,17}, {16,16,16,16,16,16,31},
    {17,27,21,21,17,17,17}, {17,25,25,21,19,19,17},
    {14,17,17,17,17,17,14}, {30,17,17,30,16,16,16},
    {14,17,17,17,21,18,13}, {30,17,17,30,20,18,17},
    {15,16,16,14,1,1,30}, {31,4,4,4,4,4,4},
    {17,17,17,17,17,17,14}, {17,17,17,17,17,10,4},
    {17,17,17,21,21,21,10}, {17,17,10,4,10,17,17},
    {17,17,10,4,4,4,4}, {31,1,2,4,8,16,31},
    {14,17,19,21,25,17,14}, {4,12,4,4,4,4,14},
    {14,17,1,2,4,8,31}, {30,1,1,14,1,1,30},
    {2,6,10,18,31,2,2}, {31,16,16,30,1,1,30},
    {14,16,16,30,17,17,14}, {31,1,2,4,8,8,8},
    {14,17,17,14,17,17,14}, {14,17,17,15,1,1,14},
    {0,4,4,0,4,4,0}, {0,0,0,31,0,0,0},
    {1,2,2,4,8,8,16}, {0,0,0,0,0,4,4},
    {14,17,1,2,4,0,4},
};

void display_label(unsigned x, unsigned y, const char *s, unsigned scale,
                   unsigned short color) {
    for (; *s && x + 5 * scale <= WIDTH; ++s, x += 6 * scale) {
        if (*s == ' ') continue;
        const char *p = strchr(ui_letters, toupper((unsigned char)*s));
        if (!p) p = strchr(ui_letters, '?');
        const uint8_t *g = ui_font[p - ui_letters];
        for (unsigned row = 0; row < 7; ++row)
            for (unsigned col = 0; col < 5; ++col)
                if (g[row] & (1u << (4 - col)))
                    fill(x + col * scale, y + row * scale, scale, scale, color);
    }
}

void display_note_restore(void) {
    uint8_t row[WIDTH * 2];
    CMD(0x2A, 0, 0, (WIDTH - 1) >> 8, (WIDTH - 1) & 255);
    CMD(0x2B, 0, CANVAS_TOP, (HEIGHT - 1) >> 8, (HEIGHT - 1) & 255);
    uint8_t cmd = 0x2c;
    gpio_put(CS, 0); gpio_put(DC, 0); write_bytes(&cmd, 1); gpio_put(DC, 1);
    for (unsigned y = 0; y < HEIGHT - CANVAS_TOP; ++y) {
        for (unsigned x = 0; x < WIDTH; ++x) {
            unsigned bit = y * WIDTH + x;
            uint8_t c = (note_bits[bit / 8] & (1u << (bit % 8))) ? 0 : 255;
            row[2 * x] = row[2 * x + 1] = c;
        }
        write_bytes(row, sizeof(row));
        if ((y & 15u) == 15u) vTaskDelay(1);
    }
    gpio_put(CS, 1);
}

void display_target(int x, int y) {
    fill(x - 12, y - 1, 25, 3, 0xf800);
    fill(x - 1, y - 12, 3, 25, 0xf800);
}

void display_toolbar(bool erasing) {
    fill(0, 0, WIDTH, CANVAS_TOP, 0x2104);
    fill(4, 6, 100, 42, erasing ? 0x4208 : 0x0470);
    fill(110, 6, 100, 42, erasing ? 0x0470 : 0x4208);
    fill(216, 6, 100, 42, 0x4208);
    display_label(24, 20, "WRITE", 2, 0xffff);
    display_label(130, 20, "ERASE", 2, 0xffff);
    display_label(242, 20, "HOME", 2, 0xffff);
}
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

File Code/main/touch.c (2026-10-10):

#include "touch.h"
#include "touch_calibration.h"
#include "board.h"
#include "display.h"
#include "ui.h"
#include "test_mode.h"
#include "driver/gpio.h"
#include "driver/spi_master.h"
#include "esp_log.h"
#include "nvs.h"
#include "nvs_flash.h"
#include "freertos/FreeRTOS.h"
#include "freertos/task.h"
#include <stdbool.h>
#include <stdint.h>
#include <stdlib.h>

static spi_device_handle_t touch;
static const char *TAG = "pen";
typedef struct { int x, y; } point_t;
static point_t origin;
static float ax, bx, ay, by;
static bool hardware_initialized;
static bool nvs_ready;

static void apply_calibration(const touch_calibration_blob_t *c) {
    origin = (point_t){c->origin_x, c->origin_y};
    ax = c->ax; bx = c->bx; ay = c->ay; by = c->by;
}

static bool load_calibration(void) {
    nvs_handle_t handle;
    esp_err_t err = nvs_open("touch", NVS_READONLY, &handle);
    if (err != ESP_OK) return false;
    touch_calibration_blob_t c;
    size_t len = sizeof(c);
    err = nvs_get_blob(handle, "cal_v1", &c, &len);
    nvs_close(handle);
    if (err != ESP_OK || len != sizeof(c) || !touch_calibration_valid(&c)) {
        ESP_LOGW(TAG, "Saved calibration missing or invalid; calibrating manually");
        return false;
    }
    apply_calibration(&c);
    ESP_LOGI(TAG, "Loaded saved touch calibration");
    return true;
}

static void save_calibration(void) {
    if (!nvs_ready) return;
    touch_calibration_blob_t c = {
        .magic = TOUCH_CAL_MAGIC, .version = TOUCH_CAL_VERSION, .size = sizeof(c),
        .origin_x = origin.x, .origin_y = origin.y,
        .ax = ax, .bx = bx, .ay = ay, .by = by,
    };
    if (!touch_calibration_valid(&c)) {
        ESP_LOGE(TAG, "Refusing to save invalid touch calibration");
        return;
    }
    nvs_handle_t handle;
    esp_err_t err = nvs_open("touch", NVS_READWRITE, &handle);
    if (err == ESP_OK) {
        err = nvs_set_blob(handle, "cal_v1", &c, sizeof(c));
        if (err == ESP_OK) err = nvs_commit(handle);
        nvs_close(handle);
    }
    if (err != ESP_OK) ESP_LOGE(TAG, "Could not save touch calibration: %s", esp_err_to_name(err));
    else ESP_LOGI(TAG, "Saved touch calibration");
}

static void pause_sample(void) { vTaskDelay(pdMS_TO_TICKS(10) + 1); }

static uint16_t adc(uint8_t cmd) {
    // XPT2046: command followed by 12-bit result, MSB first, shifted by 3.
    // PD1:PD0=00 restores power-down and PENIRQ after each conversion.
    spi_transaction_t t = {
        .flags = SPI_TRANS_USE_TXDATA | SPI_TRANS_USE_RXDATA,
        .length = 24, .tx_data = {cmd, 0, 0},
    };
    ESP_ERROR_CHECK(spi_device_polling_transmit(touch, &t));
    return (((uint16_t)t.rx_data[1] << 8) | t.rx_data[2]) >> 3 & 0x0fff;
}

static int median(int a[5]) {
    for (int i = 1; i < 5; ++i) {
        int v = a[i], j = i;
        while (j && a[j - 1] > v) { a[j] = a[j - 1]; --j; }
        a[j] = v;
    }
    return a[2];
}

static bool sample(point_t *p) {
    if (gpio_get_level(TOUCH_IRQ)) return false;
    int z1 = adc(0xb0), z2 = adc(0xc0);
    if (z1 < 100 || z2 > 4090 || z1 + 4095 - z2 < 200) return false;
    int x[5], y[5];
    for (int i = 0; i < 5; ++i) {
        (void)adc(0xd0); // Discard first sample after changing axes.
        x[i] = adc(0xd0);
        (void)adc(0x90);
        y[i] = adc(0x90);
    }
    if (gpio_get_level(TOUCH_IRQ)) return false;
    p->x = median(x); p->y = median(y);
    return p->x > 20 && p->x < 4075 && p->y > 20 && p->y < 4075;
}

static void wait_release(void) {
    int released = 0;
    while (released < 5) {
        released = gpio_get_level(TOUCH_IRQ) ? released + 1 : 0;
        pause_sample();
    }
}

static point_t capture(int x, int y) {
    display_clear();
    display_target(x, y);
    ESP_LOGI(TAG, "Hold pen on red cross (%d,%d), then lift", x, y);
    wait_release();
    point_t p = {0}, previous = {0};
    int count = 0, sum_x = 0, sum_y = 0;
    while (count < 12) {
        if (sample(&p)) {
            if (count && (abs(p.x - previous.x) > 60 || abs(p.y - previous.y) > 60)) {
                count = sum_x = sum_y = 0;
            }
            sum_x += p.x; sum_y += p.y; ++count;
            previous = p;
        } else { count = sum_x = sum_y = 0; }
        pause_sample();
    }
    p.x = sum_x / count; p.y = sum_y / count;
    // Erase target as acknowledgment; next cross appears after pen lift.
    display_clear();
    wait_release();
    return p;
}

static void calibrate(void) {
    for (;;) {
        point_t a = capture(30, 30);
        point_t b = capture(290, 30);
        point_t c = capture(30, 450);
        float ux = b.x - a.x, uy = b.y - a.y;
        float vx = c.x - a.x, vy = c.y - a.y;
        float det = ux * vy - uy * vx;
        if (det > -200000 && det < 200000) {
            ESP_LOGW(TAG, "Invalid calibration; repeat three targets");
            continue;
        }
        // Affine transform supports swapped/reversed axes automatically.
        origin = a;
        ax = 260 * vy / det; bx = -260 * vx / det;
        ay = -420 * uy / det; by = 420 * ux / det;
        touch_calibration_blob_t candidate = {
            .magic = TOUCH_CAL_MAGIC, .version = TOUCH_CAL_VERSION, .size = sizeof(candidate),
            .origin_x = origin.x, .origin_y = origin.y,
            .ax = ax, .bx = bx, .ay = ay, .by = by,
        };
        if (!touch_calibration_valid(&candidate)) {
            ESP_LOGW(TAG, "Calibration coefficients unreasonable; repeat three targets");
            continue;
        }
        break;
    }
    display_clear();
    ESP_LOGI(TAG, "Touch calibrated. Use the Home screen Recalibrate button to recalibrate.");
}
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

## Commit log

2026-09-30 Initial project commit, have the tablet screen's wired correctly, notes survive exiting the screen but not reboots. Clock not sewt up and MQTT not tested yet
    [Case.stl, penholder hole.stl]
2026-10-01 MQTT confirmed, updates when server and tabled modify list. Can add via Bluetooth to the list but do not get sent via MQTT yet and do not survive a power cycle. Bluetooth capability top change wifi c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
2026-10-08 BLE only branch for testing
    [Case.stl, penholder hole.stl]
2026-10-08 Fix BLE stalls by disabling NimBLE host flow control
    Disable host flow control after isolated testing reproduced connection
    timeouts after 13 reads or writes. Add BLE read, link timing, and packet
    pool diagnostics.
    Validated 52 writes, 118 reads, and continued traffic after reconnects.
2026-10-14 Lots of updates, case too is WIP
